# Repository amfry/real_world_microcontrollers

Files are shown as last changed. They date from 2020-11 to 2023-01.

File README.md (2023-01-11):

# Real Wold Microcontrollers - Low Power Current Logger
###### This project was completed as part of Microcontrollers for the Real World at Olin College of Engineering, Fall 2020
## Description
This board was designed to assist the [ADE Air Partners](https://www.airpartners.org/) team in evaluating how [HEPA air purifiers](https://austinair.com/shop/healthmate/) are being used by residents in East Boston. The purifiers provided the most health benefits when used 24/7 at the highest setting.  However, when deployed, purifiers are often turned to a lower setting or unplugged by users. To evalute user behavior, the board logs current continously over an extended duration.

The purifier has 4 modes have distinct current requirements, making a current logger a simple way to gain valuable data about purifier usage.  The logger was designed to be battery operated to allow data to be logged discretely.  making it low power means that data can be collected over an extended period of time. During devlopment of the board, when there was no immediate access to an air purifer, the board was tested on a standard hair dryer. The data from a test with the hair dryer can be seen below.  
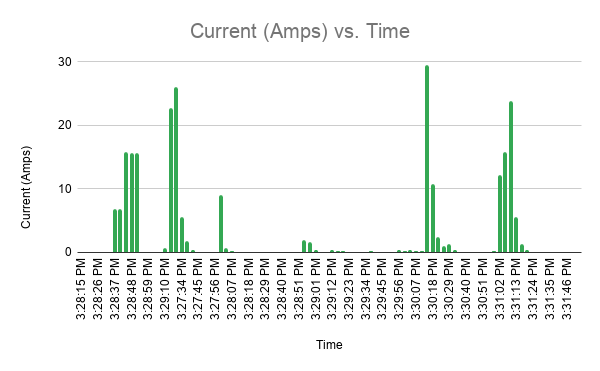
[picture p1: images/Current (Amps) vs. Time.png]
Plot
  
### Requirments
The low power currentl logger was designed to met the following technical requirments:
- Sense current running through a wall power cable.
- Keep accurate time to sync logged data with other data streams.
- Write current values and necessary time stamps to an SD card.
- Run off of battery power for a minimum of 4 weeks.

The battery pack on the board supplies 5200 mA hours and after measuring the current used while the board is logging, the board should last 57 days and weeks assuming a nominal current of 3.78 mA when the sample rate every 5 minutes.
## Design
### Schematic
The board layout has 7 major components:
- [Processor](https://www.sparkfun.com/products/11114): The arduino mini pro 3.3v was chosen because it was compatible with the power requirments of the other module that were being selected. It's low clock speed makes it a good canidate for this low power project and the DIY intrnet community has used in extensively in data logging projects.
  
- [RTC](https://www.adafruit.com/product/3013): The DS3231 is a precise RTC with it's own battery and a temperature sensor to to compensate for crsyal frequency changes as the temperature changes. It communicates with the processor over I2C. In this application, the time is set at compile time using the arduino IDE's compiler.  
  
- [SD Card module](https://www.sparkfun.com/products/544): This simple micro-SD module works over SPI and was easier to solder to the board the breakout rather than wokring with the raw socket.  
  
- [Display module](https://www.adafruit.com/product/4440#technical-details): This display module communicated over I2C and it's relatively small screen was sufficient for creating a minimal user interface to display the set time, status of the SD, and battery levels during module intergration.  
  
- [Buck/Boost Converter](https://www.sparkfun.com/products/15208) This board was choosen due to it's high efficieny at providing a constant 3.3 input voltage. In the board, this is connected to 2 18650 batteries that are in parallel to make up the power source for the project.  
  
- [Current sensor](https://learn.openenergymonitor.org/electricity-monitoring/ct-sensors/yhdc-sct-013-000-ct-sensor-report) The SCT013 sensor is able to log current data without having to slice any wire and comes with it's own arduino library to process that analog signal which made it a good pick for this project.

The schematic and board designed were completed in KiCAD and can be see [here](https://github.com/amfry/real_world_microcontrollers/blob/main/hardware/low_current_data_logger.zip).  
### Board
Below is the populated final version of the low power current logger. The board was manufactured by [JLCPCB](https://jlcpcb.com/) and was assembled with hand soldereding.  The board is 2-layer with all THT componenets. The board layout and assembly can be seen below.  

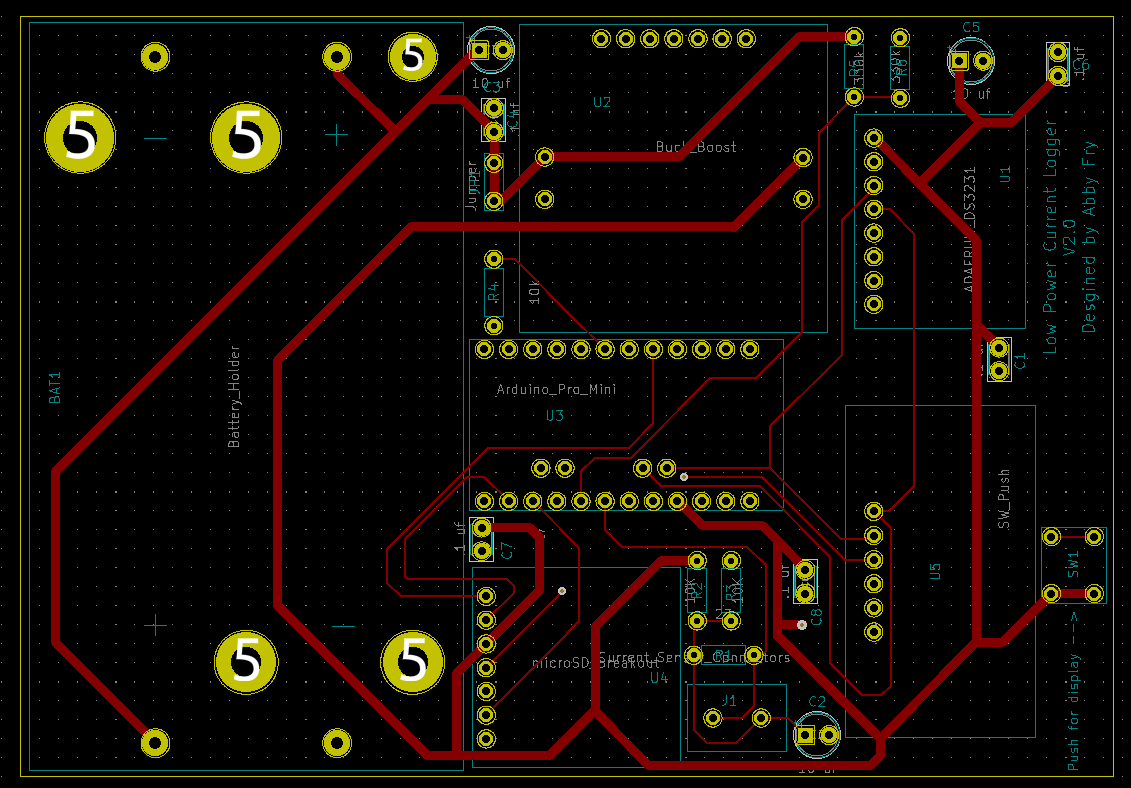
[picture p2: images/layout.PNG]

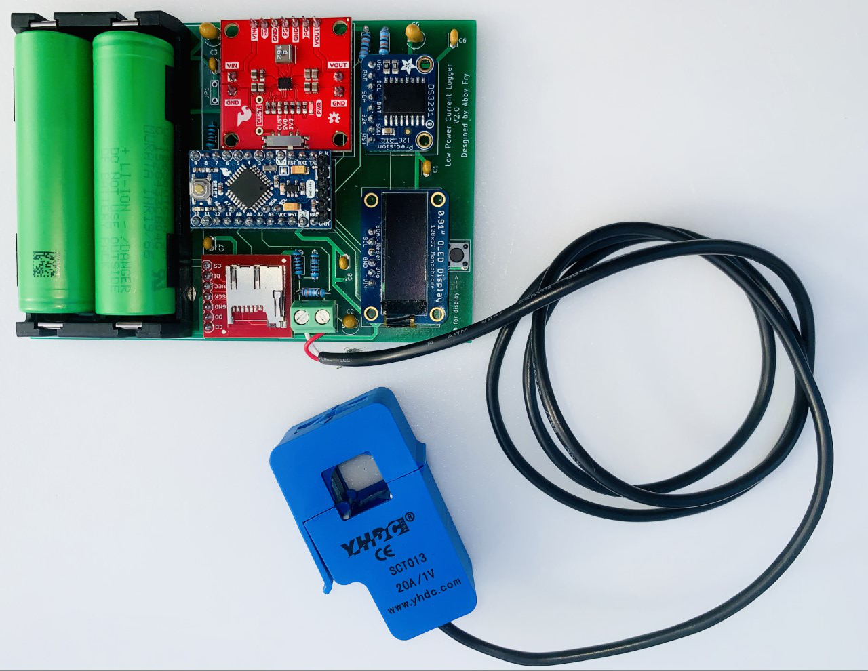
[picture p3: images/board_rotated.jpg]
  

### BOM & Cost
A motivation for designing this board for the [ADE Air Partners](https://www.airpartners.org/) team was to create a lower cost alternative to the current products used for current data logging. Products that can do that such as a [HOBO data logger](https://www.onsetcomp.com/products/data-loggers/ux120-006m/), but these products are bulky, expensive (> $200 each), and generally designed for industrial applications. This means that the baord developed could save the team over a 100 dollars for each logging unit. Additional cost reduction could be implemnted such as transition to using just the processor chip in the arduino mini pro and manufacturing the board in bulk.  
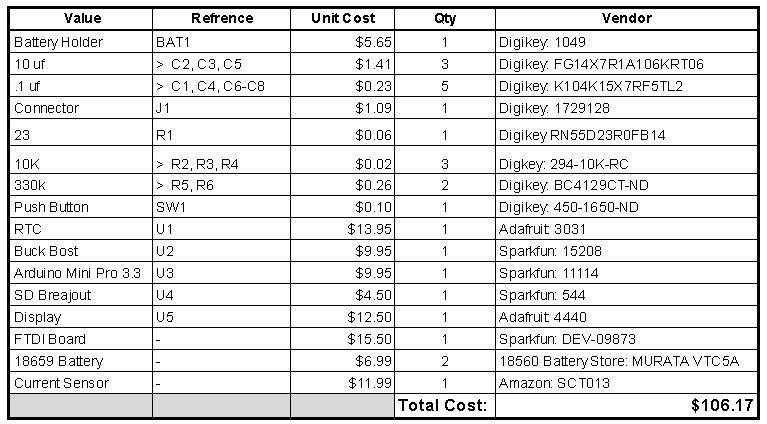
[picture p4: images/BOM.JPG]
BOM

### Next Steps
To improve the utility of this board for it's inteded purpose further development is need.
- User interface: The board has a display and push button user interface that are not currently being used. In doing software development, the large size of the display library made the display difficult to integrate with other core functionality. More research and development into how to implemnt display functionality with low memory avaliable is needed.
- Low power improvments: While the board could run for ~57 days many amount of time with the current battery pack and software, extending the battery life of the board would allow more holistic data to be collected on air purifer usage. Implemnting "sleep mode" in between data samples and expanding the battery pack should be complete to imporve the board.
###### Special thanks to Stan Reifiel for his guidance throughout this project.

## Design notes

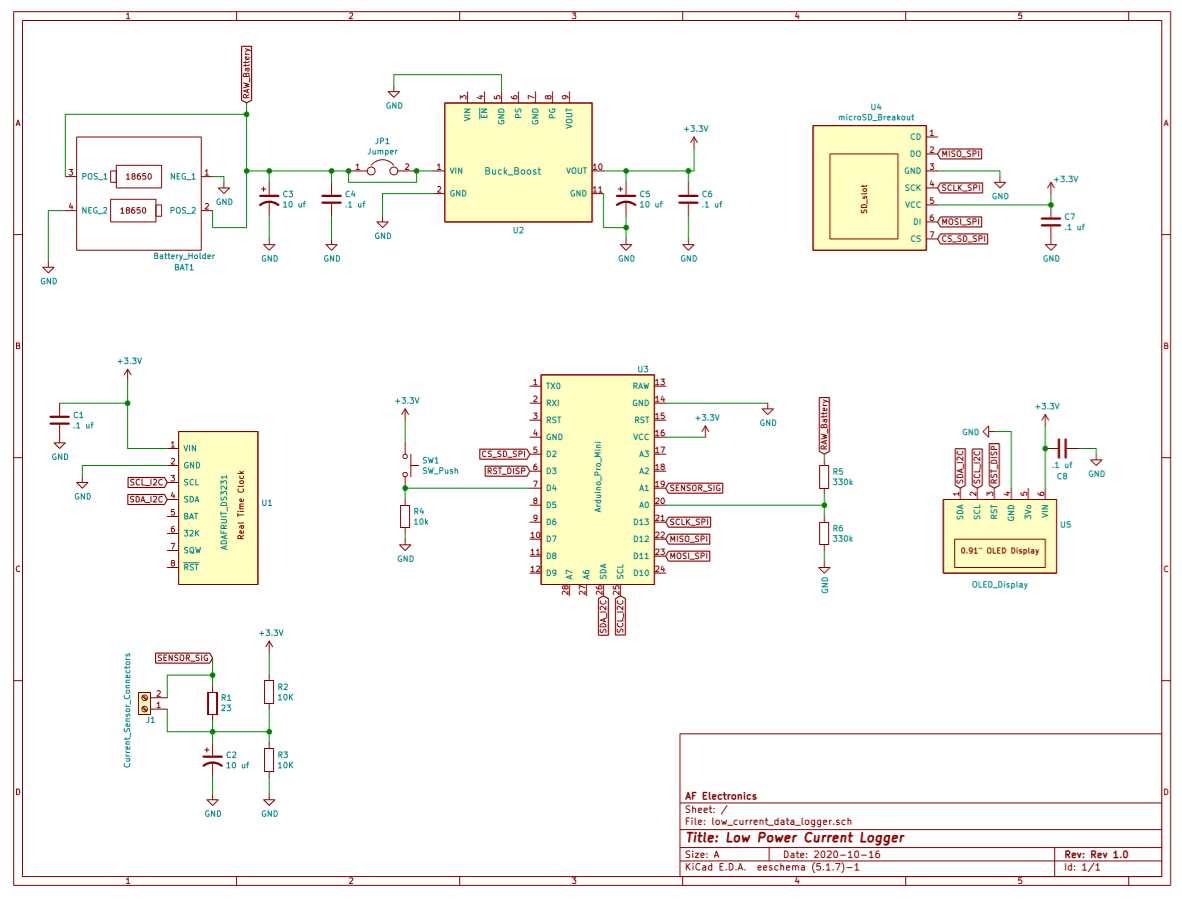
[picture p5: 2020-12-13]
images/Schem.PNG

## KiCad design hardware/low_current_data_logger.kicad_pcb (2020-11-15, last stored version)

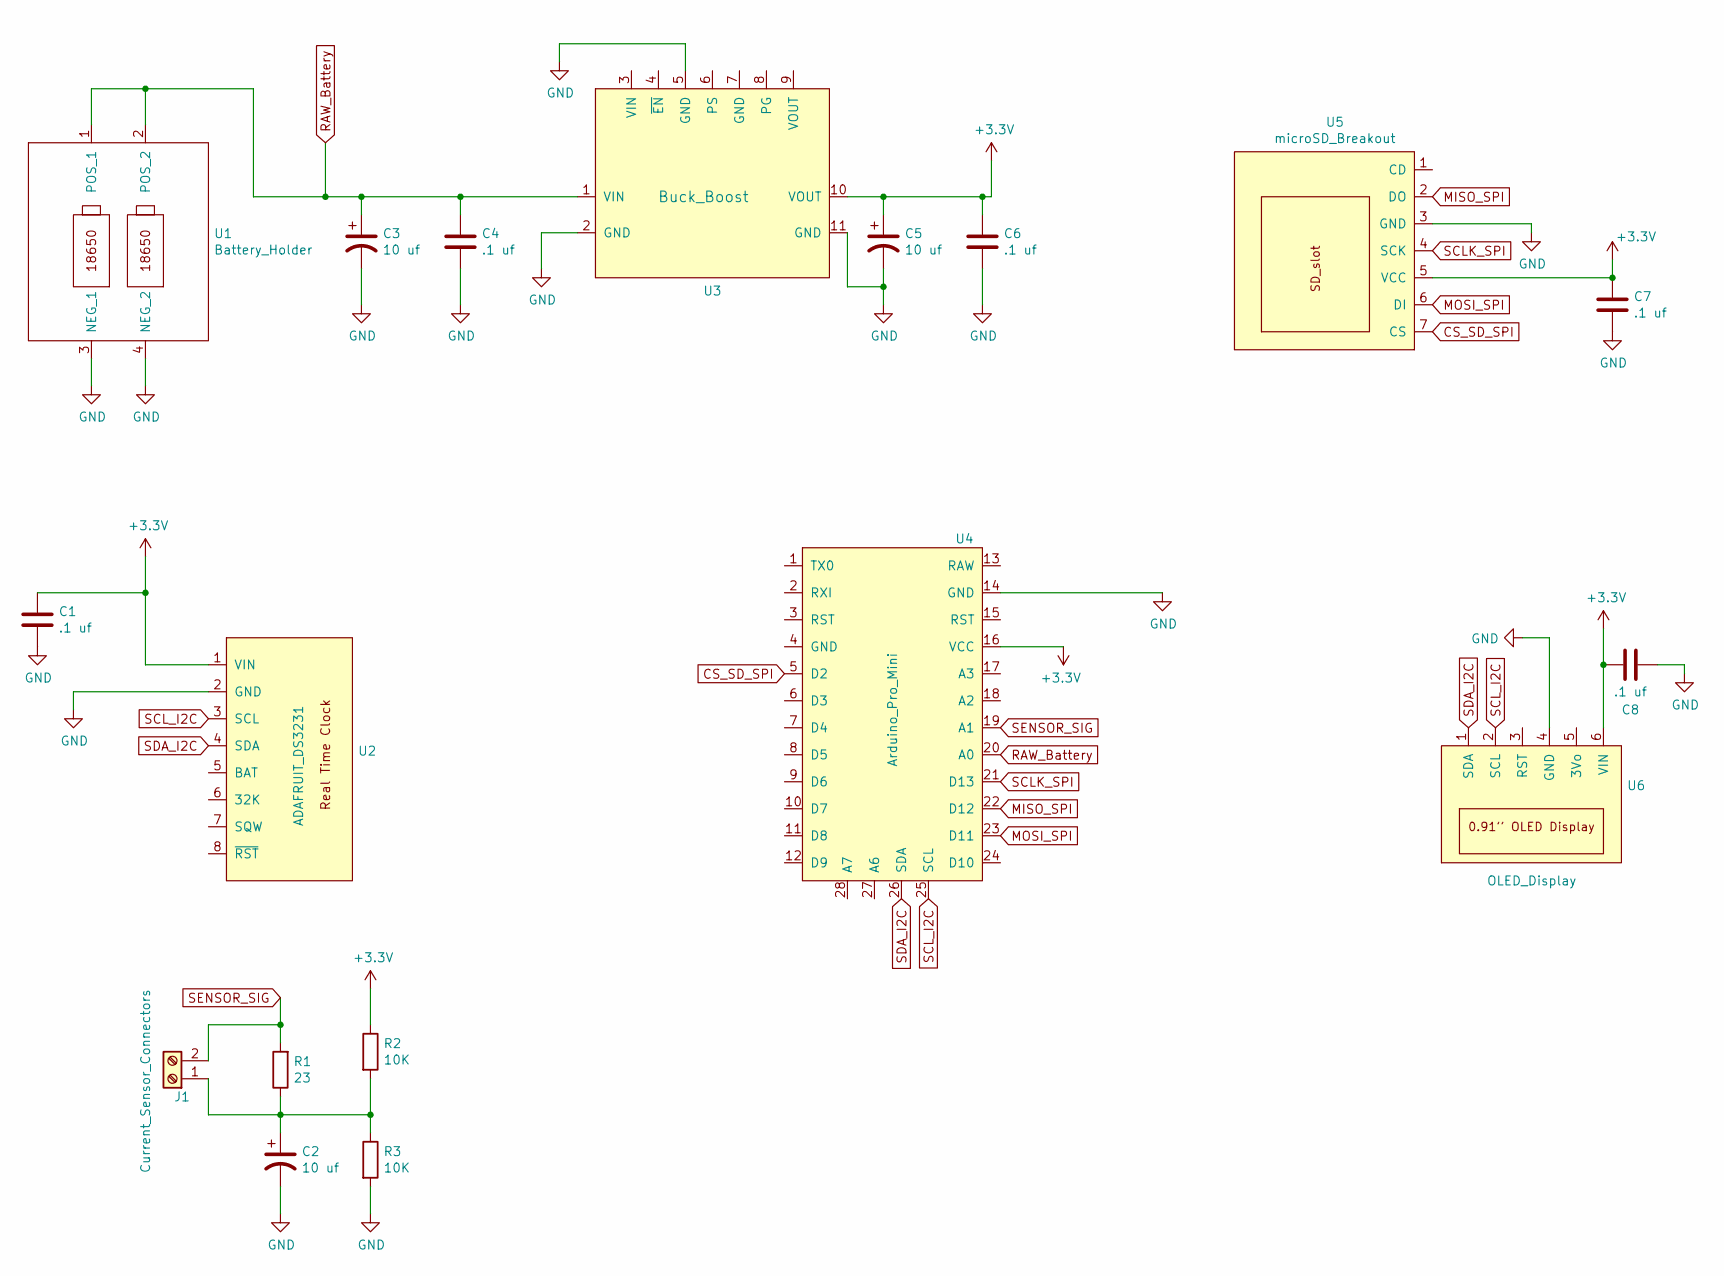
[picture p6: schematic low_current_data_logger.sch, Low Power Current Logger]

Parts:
C1, C4, C6, C7, C8: .1 uf; C_Disc_D4.7mm_W2.5mm_P5.00mm
C2, C3, C5: 10 uf; CP_Radial_Tantal_D4.5mm_P2.50mm
J1: Current_Sensor_Connectors; TerminalBlock_4Ucon_1x02_P3.50mm_Vertical
R1: 23; resistor_THT
R2, R3: 10K; resistor_THT
U1: Battery_Holder; 36-1049-ND
U2: ADAFRUIT_DS3231; adafruit_RTC
U3: Buck_Boost; buck_boost
U4: Arduino_Pro_Mini; arduino_mini_pro
U5: microSD_Breakout; sd_mod
U6: OLED_Display; oled_display

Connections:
+3V3: C1.1, C5.1, C6.1, C7.1, C8.1, R2.1, U2.1 (VIN), U3.10 (VOUT), U4.16 (VCC), U5.5 (VCC), U6.6 (VIN)
CS_SD_SPI: U4.5 (D2), U5.7 (CS)
GND: C1.2, C2.2, C3.2, C4.2, C5.2, C6.2, C7.2, C8.2, R3.2, U1.3 (NEG_1), U1.4 (NEG_2), U2.2 (GND), U3.2 (GND), U3.5 (GND), U3.11 (GND), U4.14 (GND), U5.3 (GND), U6.4 (GND)
MISO_SPI: U4.22 (D12), U5.2 (DO)
MOSI_SPI: U4.23 (D11), U5.6 (DI)
unnamed: C2.1, J1.1, R1.1, R2.2, R3.1
RAW_Battery: C3.1, C4.1, U1.1 (POS_1), U1.2 (POS_2), U3.1 (VIN), U4.20 (A0)
SCLK_SPI: U4.21 (D13), U5.4 (SCK)
SCL_I2C: U2.3 (SCL), U4.25 (SCL), U6.2 (SCL)
SDA_I2C: U2.4 (SDA), U4.26 (SDA), U6.1 (SDA)
SENSOR_SIG: J1.2, R1.2, U4.19 (A1)

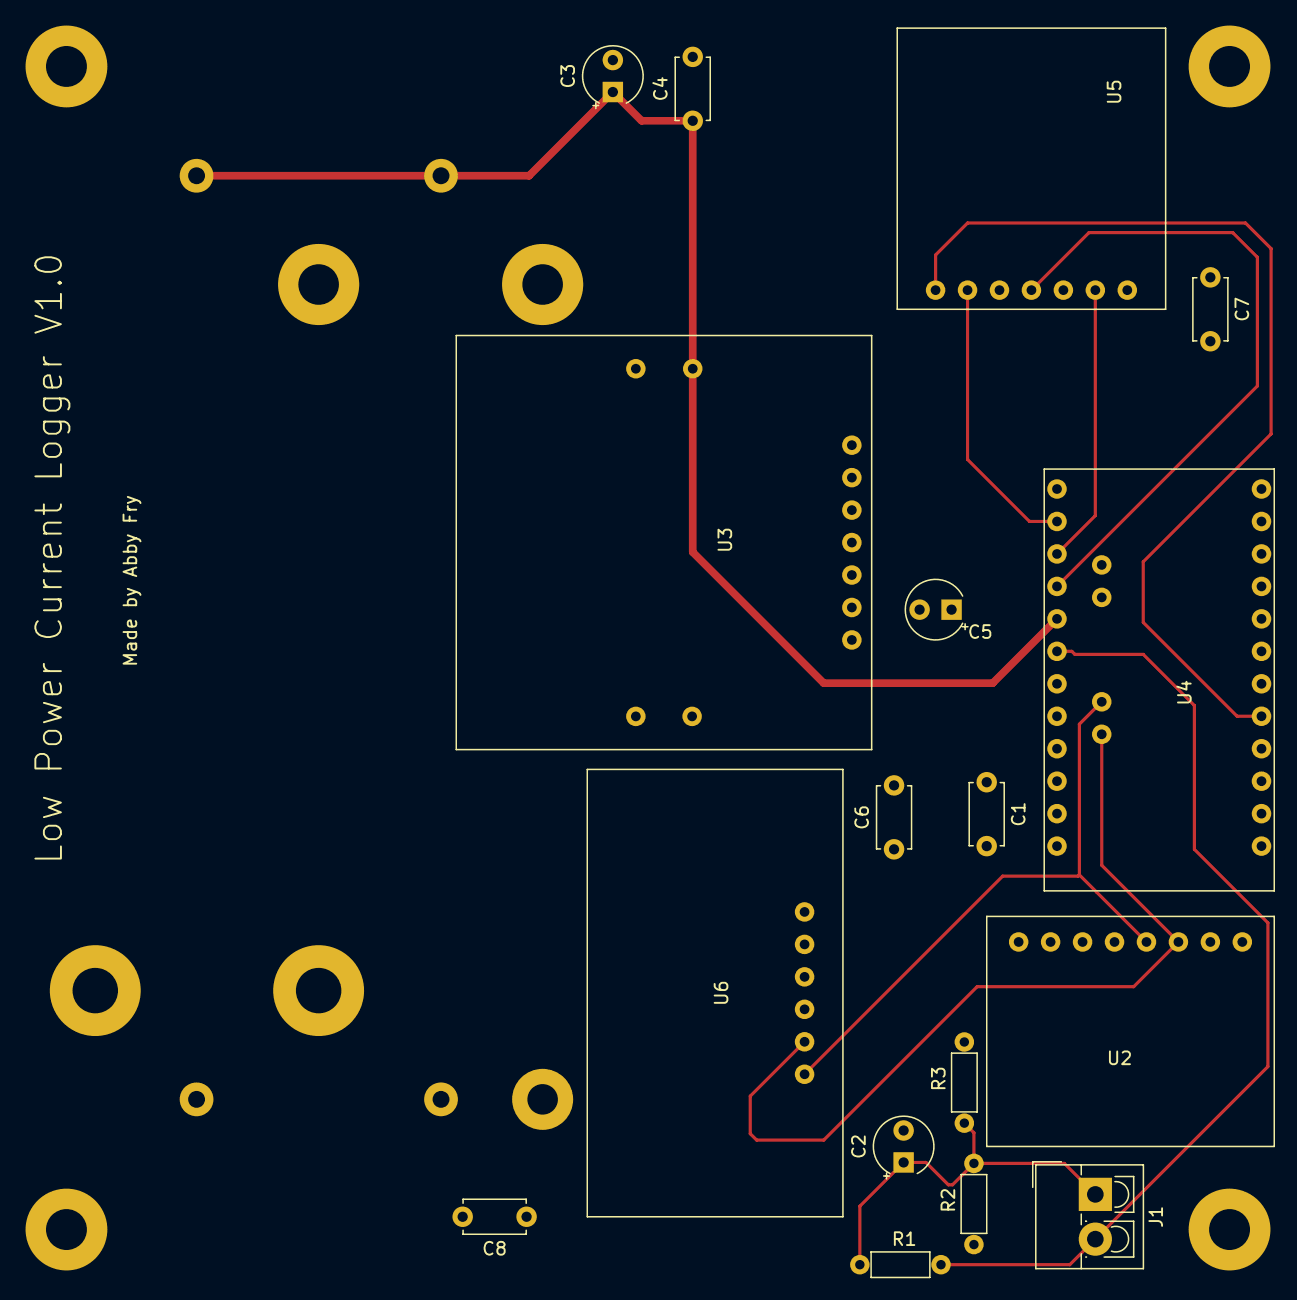
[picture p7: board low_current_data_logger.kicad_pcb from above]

Board: 4 copper layers, 18 parts (1 on the bottom side), 11 nets.

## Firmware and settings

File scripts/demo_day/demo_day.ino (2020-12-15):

/*This script was developed by Abby Fry, Fall 2020 as part of Real World Microcontrollers @ Olin College of Engineering *\


#include "EmonLib.h"
#include <SPI.h>
#include <SD.h>
#include <DS3231.h>
#include <Wire.h>
#include <TimeLib.h>
#include <DS1307RTC.h>

int sample_rate=5000; // Sampling rate

// Battery Protection Setup
const int raw_battery_pin = 0;

// RTC Setup
const char *monthName[12] = {
  "Jan", "Feb", "Mar", "Apr", "May", "Jun",
  "Jul", "Aug", "Sep", "Oct", "Nov", "Dec"
};

tmElements_t tm;

// Current Sensor Setup
EnergyMonitor emon1;

// SD Setup
File dataFile;
const int chipSelect = 2;

void setup()
{
  Serial.begin(115200);
  
  // RTC Initalization
  bool parse=false;
  bool config=false;
  
  // get the date and time from compiler
  if (getDate(__DATE__) && getTime(__TIME__)) {
    parse = true;
    // and configure the RTC with this info
    if (RTC.write(tm)) {
      config = true;
    }
  }
    
  // Current Sensor Intialization
  emon1.current(1, 111.1); // Current: input pin, calibration.

  if (!SD.begin(chipSelect)) {
  Serial.println("initialization failed!");
  while (1);
  }
  Serial.println("initialization done.");
}

void loop()
{
double Irms = emon1.calcIrms(1480);  // Calculate Irms 
write_sd_val(Irms);
write_sd_string(",");
write_date();
write_sd_string(",");
write_time();
sd_newline();
delay(sample_rate);  
}



// SD Functions
  void write_sd_val(float val){
  //Write float values (like current) to SD card
  dataFile.close();
  dataFile = SD.open("test.txt", FILE_WRITE);
  if (dataFile) {
    dataFile.print(val);
    dataFile.close();
  }
 }

void write_sd_datetime(int val){
// Write time & date values as int
  dataFile.close();
  dataFile = SD.open("test.txt", FILE_WRITE);
  if (dataFile) {
    dataFile.print(val);
    dataFile.close();
  }
}

void write_sd_string(String val){
// Write strings to SD card to create .csv formatting
  dataFile.close();
  dataFile = SD.open("test.txt", FILE_WRITE);
  if (dataFile) {
    Serial.println("success");
    dataFile.print(val);
    dataFile.close();
}
}

void sd_newline(void){
// Write a newline to SD file to keep .csv format
  dataFile.close();
  dataFile = SD.open("test.txt", FILE_WRITE);
  if (dataFile) {
    //Serial.println("success");
    dataFile.println();
    dataFile.close();
}
}

// RTC Functions
bool getTime(const char *str)
// retrieve time from compiler
{
  int Hour, Min, Sec;
  if (sscanf(str, "%d:%d:%d", &Hour, &Min, &Sec) != 3) return false;
  tm.Hour = Hour;
  tm.Minute = Min;
  tm.Second = Sec;
  return true;
}

bool getDate(const char *str)
//retreive date from compiler
{
  char Month[12];
  int Day, Year;
  uint8_t monthIndex;

  if (sscanf(str, "%s %d %d", Month, &Day, &Year) != 3) return false;
  for (monthIndex = 0; monthIndex < 12; monthIndex++) {
    if (strcmp(Month, monthName[monthIndex]) == 0) break;
  }
  if (monthIndex >= 12) return false;
  tm.Day = Day;
  tm.Month = monthIndex + 1;
  tm.Year = CalendarYrToTm(Year);
  return true;
}

void write2digits(int number){
// Write date/time values to SD card 
  if (number >= 0 && number < 10) {
    write_sd_string("0");
  }
  write_sd_datetime(number);
}

void write_date(void){
  write2digits(tm.Day);
  write_sd_string("-");
  write2digits(tm.Month);
  write_sd_string("-");
  write2digits(tmYearToCalendar(tm.Year));
  }

void write_time(void){
  write2digits(tm.Hour);
  write_sd_string(":");
  write2digits(tm.Minute);
  write_sd_string(":");
  write2digits(tm.Second);
  }

//Battery Functions
  float read_raw_battery(void){
  // Check on battery voltage
  float raw_v_val = analogRead(raw_battery_pin) * (3.6/1024);
  float scaled_v_val = (raw_v_val /(3.6/2)) * 3.3;
  return scaled_v_val;
  }

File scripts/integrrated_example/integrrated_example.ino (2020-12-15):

#include <Wire.h>
#include <Adafruit_GFX.h>
#include <Adafruit_SSD1306.h>
#include <SPI.h>
#include <SD.h>
#include <DS3231.h>

// RTC Setup
DS3231 Clock;
bool Century=false;
bool h12;
bool PM;

// SD Setup
Sd2Card card;
File dataFile;
const int chipSelect = 2;

// Display Setup
#define SCREEN_WIDTH 128 // OLED display width, in pixels
#define SCREEN_HEIGHT 32 // OLED display height, in pixels
#define OLED_RESET     3 // Reset pin #
Adafruit_SSD1306 display(SCREEN_WIDTH, SCREEN_HEIGHT, &Wire, OLED_RESET);

// Battery Protection Setup
const int raw_battery_pin = 0;

// Current Sensor setup
//#include "EmonLib.h"
int current_pin = 1;

void setup() {
  // Display initialization 
  if(!display.begin(SSD1306_SWITCHCAPVCC, 0x3C)) { // Address 0x3C for 128x32
    for(;;); // Don't proceed, loop forever
  }
  display.display();
  delay(500); 
  display.clearDisplay();
  draw_single_entry("AIR PARTNERS",500, 1);
  
  // Start-up Checks
  draw_single_entry("Bat. Voltage: " + String(read_raw_battery()),2000,1); //Show Battery level
  draw_single_entry("Current Time:" + String(get_time_now()),2000,1);// Current Time
  draw_single_entry("SD Status:" + String(sdcard_status()),2000,1);// SD status

  //delay(3000);
  // Init Sensor
  //emon1.current(current_pin, 111.1);
}

void loop() {
   draw_single_entry("SD Status:" + String(sdcard_status()),2000,1);// SD status
  delay(1000);
  //write_sd(get_current_val());
  
}
//// Current Sensor Functions
float get_current_val(void){
  return analogRead(current_pin);
  }

// Display Functions
void draw_single_entry(String value, int hold_time, int scale){
  display.clearDisplay();
  display.setTextSize(scale);             // Normal 1:1 pixel scale
  display.setTextColor(SSD1306_WHITE);        // Draw white text
  display.setCursor(0,0);             // Start at top-left corner
  display.println(value);
  display.display();
  delay(hold_time);
  display.clearDisplay();
  }

//Battery Functions
  float read_raw_battery(void){
  // Due to voltage divider, the raw_battery max value is 2.5
  float raw_v_val = analogRead(raw_battery_pin) * (3.6/1024);
  float scaled_v_val = (raw_v_val /(3.6/2)) * 3.3;
  return scaled_v_val;
  }

// SD Functions
  int sdcard_status(void){
  int val;
  if (!card.init(SPI_HALF_SPEED, chipSelect)&& (!SD.begin(chipSelect))) {
    val = 0;
  } else {
    val = 1;
  }
  return val;
  }

 void write_sd(float val){
  dataFile.close();
  dataFile = SD.open("test.txt", FILE_WRITE);
  if (dataFile) {
    //draw_single_entry("Sucess!",500,1);
    dataFile.println(String(val));
    dataFile.close();
  }
  else{
    //draw_single_entry("Write Fail!",500,1);
    }
 }

// RTC Functions
String get_time_now(void){
  int pre;
  if (Century) {      // Won't need this for 89 years.
    pre = 1;
  } else {
    pre = 0;}
  int year_clk = Clock.getYear();
  int month_clk = Clock.getMonth(Century);
  int day_clk = Clock.getDate();
  int hour_clk = Clock.getHour(h12, PM);
  int min_clk = Clock.getMinute();
  int sec_clk = Clock.getSecond();
  return  "2" + String(pre)+ String(year_clk,DEC) + " " + String(month_clk,DEC); /*+ " " + String(day_clk,DEC)
  + ": " + String(hour_clk,DEC)+ " " + String(min_clk,DEC)+ " " + String(sec_clk,DEC); */
 }
